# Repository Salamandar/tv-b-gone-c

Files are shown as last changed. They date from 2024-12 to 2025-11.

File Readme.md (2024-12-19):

# TV-B-Gone-C

This is a compact USB-C powered TV-B-Gone.

See <https://www.tvbgone.com> for details.

Thank you Mitch Altman for this amazing project!

## Flashing

It is suggested to use an Arduino as ISP.

Burn the FUSE bits for the external 8MHz oscillator option:
```
avrdude -cavrisp -b 19200 -P /dev/ttyUSB0 -pattiny85 -U lfuse:w:0xfe:m -U hfuse:w:0xdf:m -U efuse:w:0xff:m
```

Then flash the firmware:
```
avrdude -cavrisp -b 19200 -P /dev/ttyUSB0 -pattiny85 -U flash:w:tvbgone.hex
```

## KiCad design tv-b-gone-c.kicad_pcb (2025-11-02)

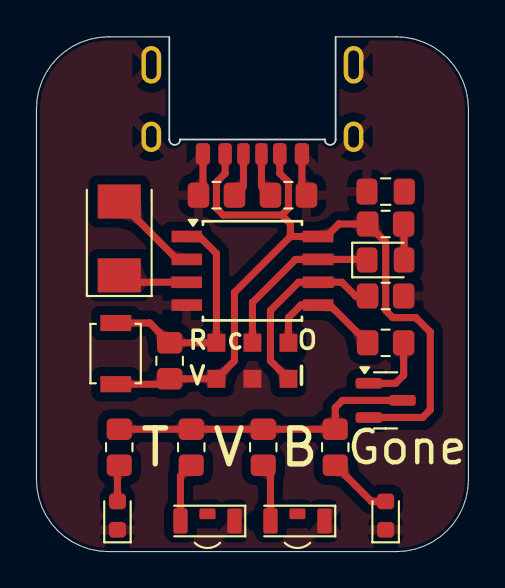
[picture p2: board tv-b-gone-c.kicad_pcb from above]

Board: 2 copper layers, 24.0 x 28.6 mm, 27 parts (0 on the bottom side), 17 nets.

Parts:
C1: 100n; C_0805_2012Metric_Pad1.18x1.45mm_HandSolder
D1: D; LED_0805_2012Metric_Pad1.15x1.40mm_HandSolder
D2, D5: LED; LED_Wurth_15411494AA570
D3, D4: LED; LED_0603_1608Metric
J2: USB4515; USB4515-GF-A
Q5: MMBT2907A; SOT-23
R1, R7, R8, R9, R10: 100; R_0805_2012Metric_Pad1.20x1.40mm_HandSolder
R2, R4: 10k; R_0805_2012Metric_Pad1.20x1.40mm_HandSolder
R3: min. 680; R_0805_2012Metric_Pad1.20x1.40mm_HandSolder
R5, R6: 5k1; R_0805_2012Metric_Pad1.20x1.40mm_HandSolder
SW1: SW_SPST; SW_SPST_B3U-1000P
TP1: MOSI; TestPoint_Pad_1.0x1.0mm
TP2: MISO; TestPoint_Pad_1.0x1.0mm
TP3: SCK; TestPoint_Pad_1.0x1.0mm
TP4: ~{RST}; TestPoint_Pad_1.0x1.0mm
TP5: 5V; TestPoint_Pad_1.0x1.0mm
TP6: GND; TestPoint_Pad_1.0x1.0mm
U1: ATtiny85V-10S; SOIC-8W_5.3x5.3mm_P1.27mm
Y1: 8MHz; Crystal_SMD_Abracon_ABM3-2Pin_5.0x3.2mm

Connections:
+5V: C1.1, J2.A9 (VBUS), J2.B9 (VBUS), Q5.2 (E), R3.1, R4.1, SW1.1 (A), TP5.1, U1.8 (VCC)
/MISO: R2.1, TP2.1, U1.6 (PB1)
/MOSI_LEDs: R1.1, TP1.1, U1.5 (AREF/PB0)
/SCK_LED: D1.1 (K), TP3.1, U1.7 (PB2)
/~RST: R4.2, SW1.2 (B), TP4.1, U1.1 (~RESET/PB5)
GND: C1.2, D2.1 (K), D3.1 (K), D4.1 (K), D5.1 (K), J2.A12 (GND), J2.B12 (GND), J2.S1 (SHIELD), R2.2, R5.2, R6.2, TP6.1, U1.4 (GND)
unnamed: D1.2 (A), R3.2
unnamed: D2.2 (A), R8.1
unnamed: D3.2 (A), R7.1
unnamed: D4.2 (A), R10.1
unnamed: D5.2 (A), R9.1
unnamed: J2.A5 (CC1), R6.1
unnamed: J2.B5 (CC2), R5.1
unnamed: Q5.1 (B), R1.2
unnamed: Q5.3 (C), R7.2, R8.2, R9.2, R10.2
unnamed: U1.2 (XTAL1/PB3), Y1.2
unnamed: U1.3 (XTAL2/PB4), Y1.1

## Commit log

2024-12-18 Update values post-fab, fix trace
    [tv-b-gone-c.kicad_pcb, tv-b-gone-c.kicad_sch]
2025-11-02 Add reset button, use mosfet
    [tv-b-gone-c.kicad_pcb, tv-b-gone-c.kicad_sch]
